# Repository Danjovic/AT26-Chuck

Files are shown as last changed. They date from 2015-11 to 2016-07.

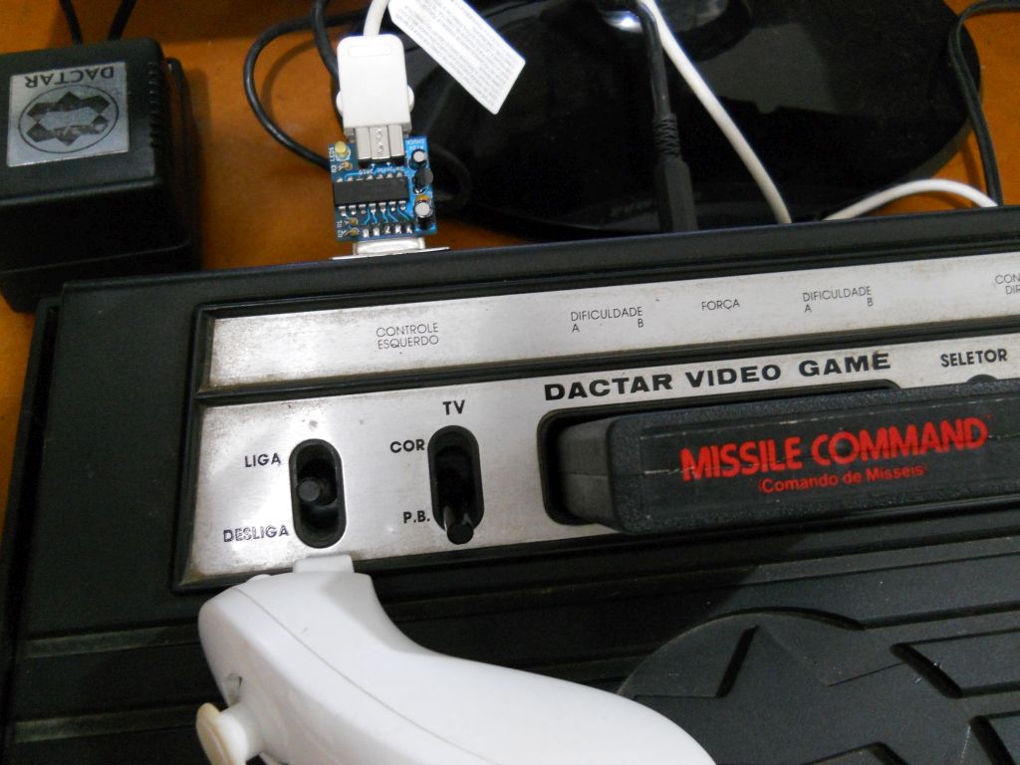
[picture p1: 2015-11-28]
Doc/DSCN6053.jpg

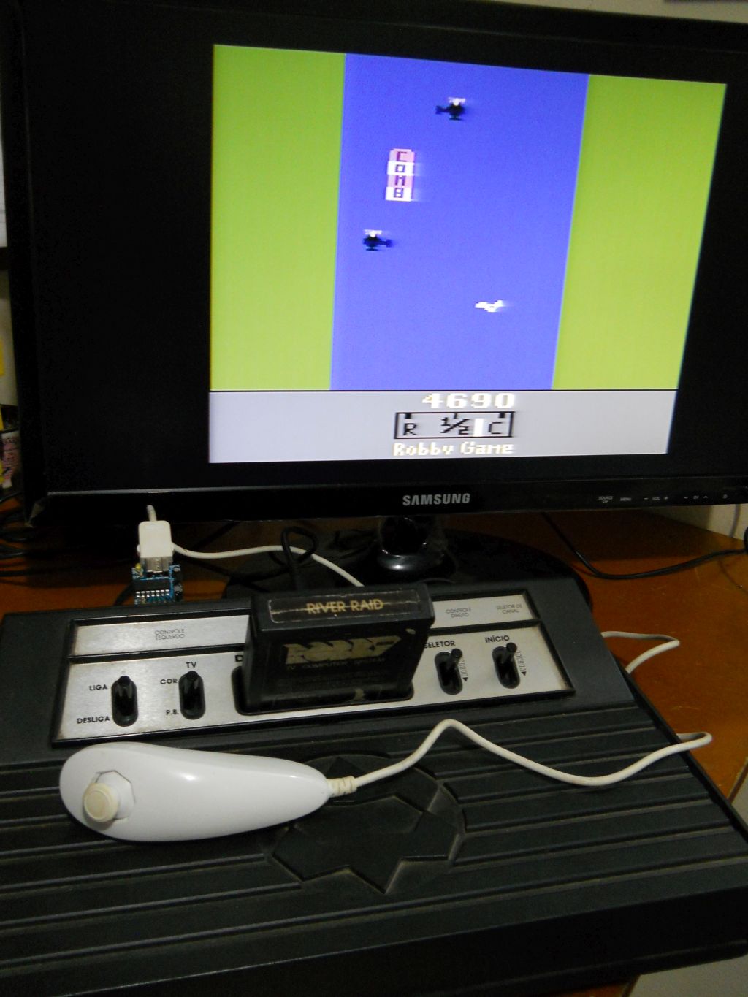
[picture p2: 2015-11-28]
Doc/DSCN6057.jpg

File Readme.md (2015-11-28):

# AT-26 Chuck
This project allow the use of a Wii Nunchuck for playing games with Atari 2600 and other video-games with compatible joystick port (like ZX Spectrum w/ Kempston).

The heart of the circuit is a PIC microcontroller that converts I2C data from Wii Nunchuck. into pressing of switches on the Atari Joystick.

The device can be programmed into several modes of operation, with or without the accelerometers and auto-fire. The configuration is stored in EEPROM.

All components are through hole and the board can be easily built at home.

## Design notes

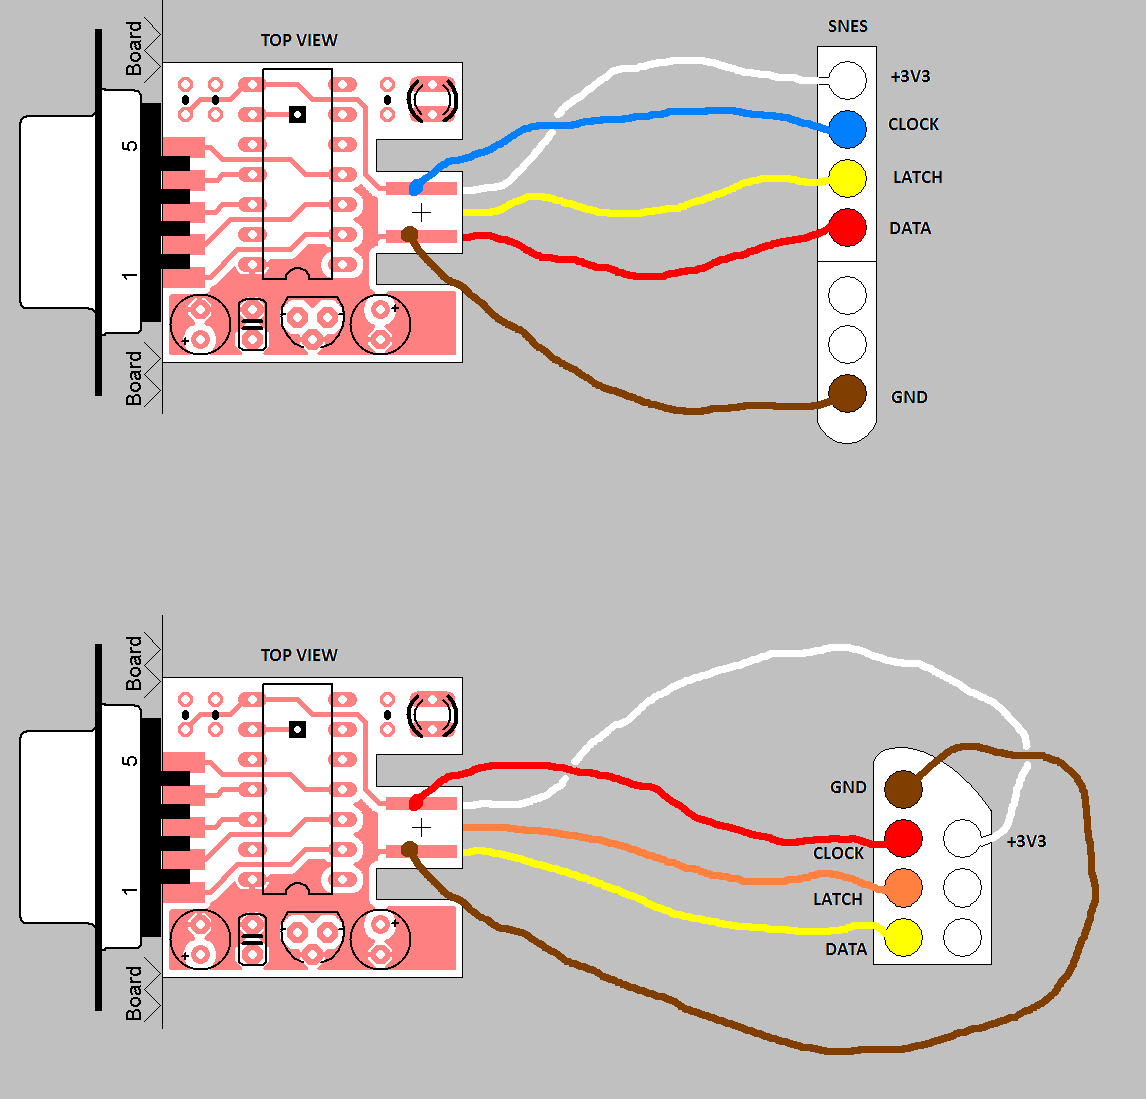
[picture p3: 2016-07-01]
Doc/Board Connections SNES - NES.png

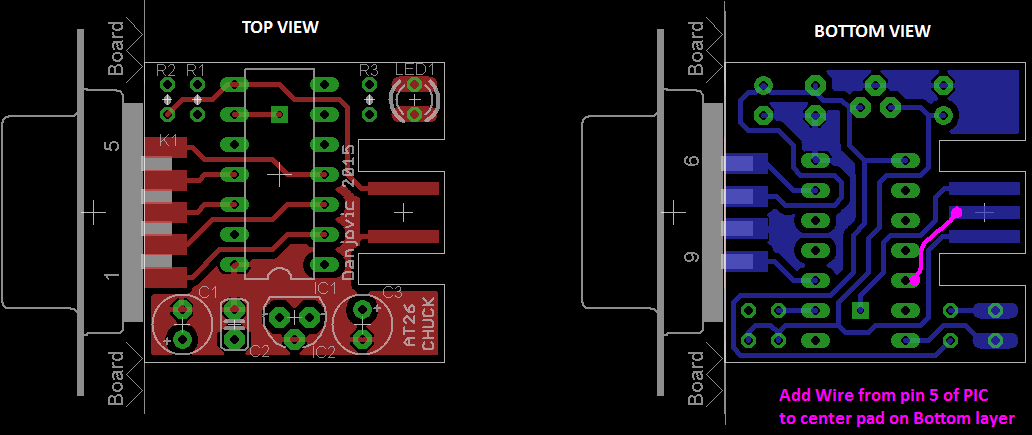
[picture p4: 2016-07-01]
Doc/Board MOD for SNES firmware.png

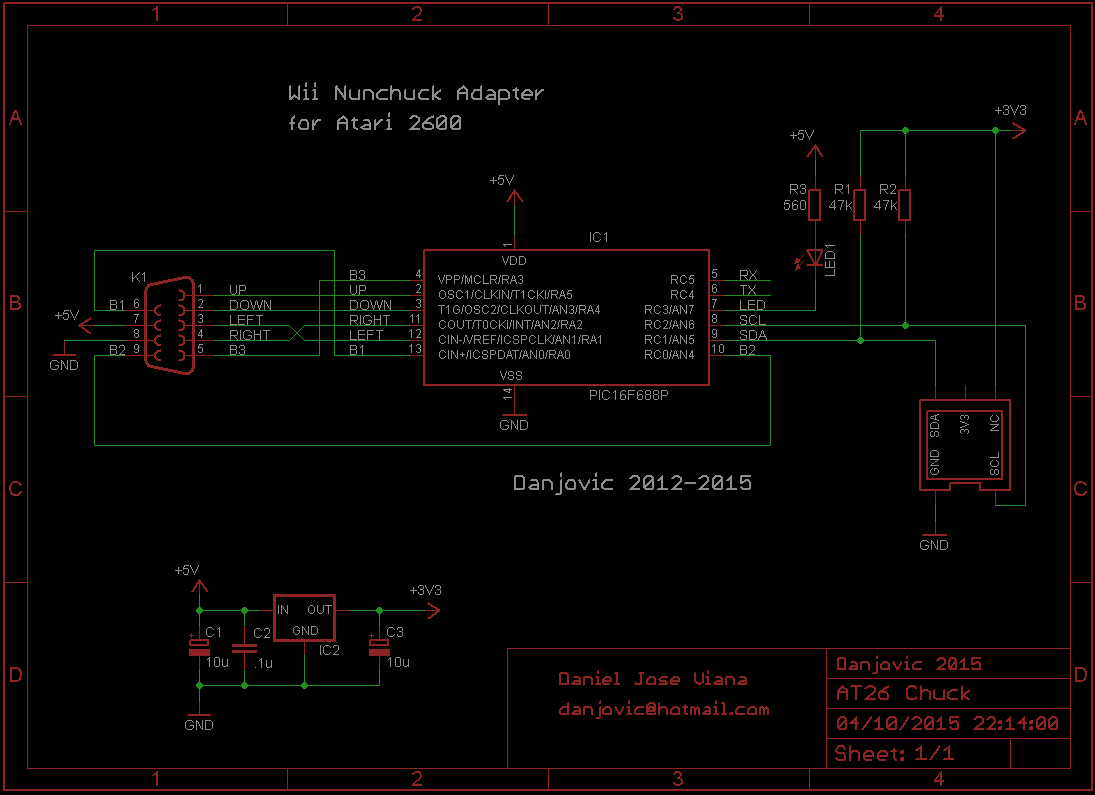
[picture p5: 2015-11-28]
Doc/AT26 Chuck-sch.png

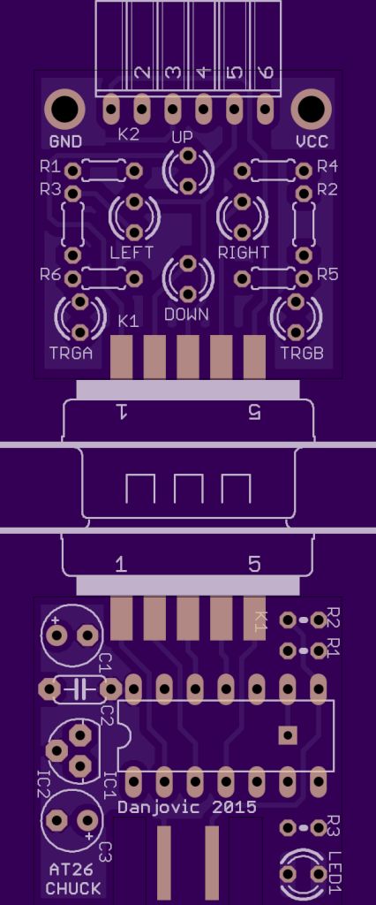
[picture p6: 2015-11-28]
Doc/AT26 both.jpg

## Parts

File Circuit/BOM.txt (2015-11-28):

# AT26-Chuck Bill of Materials

IC1   - PIC16F688, DIP14 Package PIC microcontroller 4K Flash, 14 pins
IC2   - 78L33 Voltage Regulator, TO92 package
LED1  - 3mm LED, Yellow 3mm LED, Yellow
C1,C3 - 10uF/16V Electrolytic Capacitor, radial
C2    - 100nf Polyester/Ceramic capacitor
R1,R2 - 47K 1/4W Resistor, 1/4 Watt
R3    - 560 Ohms 1/4W Resistor, 1/4 Watt
K1    - DB-9 Female SUBD connector, 9 pins, female, pins for soldering

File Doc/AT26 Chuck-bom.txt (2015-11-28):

Partlist exported from C:/Users/user/Desktop/Projetos/PIC/TK-Chuck/AT26 Chuck.sch at 04/10/2015 22:17:50

Qty Value      Device                  Part ID 
1   78L33      Voltage Regulator       IC2   
1   SUB09D     DB-9 Female Connector   K1    
1   LED        LED 3mm Yellow          LED1  
1   .1u        Ceramic Capacitor       C2 
2   10u        Electrolytic Capacitor  C1, C3
2   47k        1/8W Resistor           R1, R2
1   560        1/8W Resistor           R3    
1   PIC16F688P Microcontroller DIP14   IC1

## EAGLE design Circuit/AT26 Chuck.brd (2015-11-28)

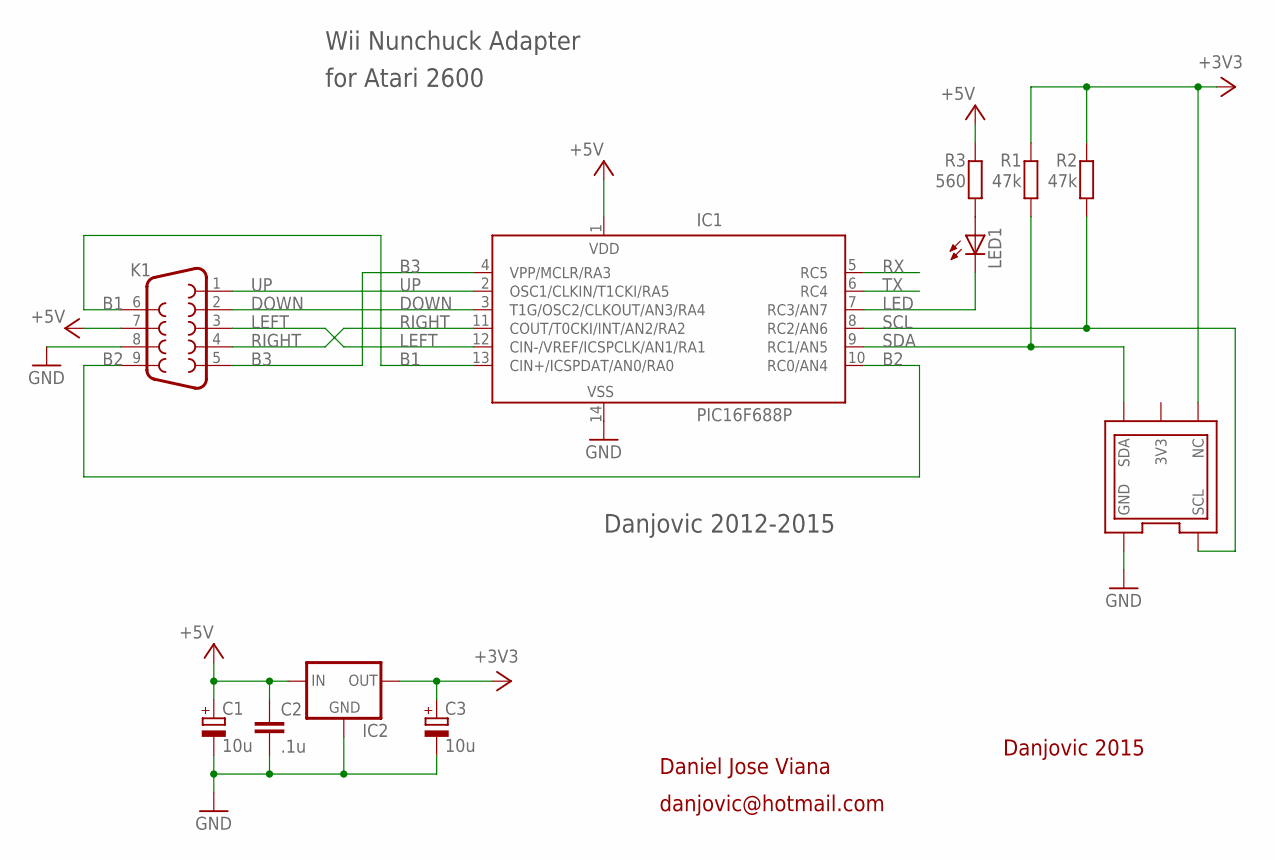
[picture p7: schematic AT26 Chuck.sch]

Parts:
C1, C3: 10u; E2,5-5
C2: .1u; C025-024X044L
IC1: PIC16F688P; DIL14
IC2: 78LXX78LXX_L; 78LXX_L
K1: F09D
LED1: LED3MM
R1, R2: 47k; 0204V
R3: 560; 0204V
U$1: NUNCHUCK; NUNCHUCK_SLOT

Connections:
+3V3: C3.+, IC2.OUT, R1.2, R2.2, U$1.NC
+5V: C1.+, C2.1, IC1.1 (VDD), IC2.IN, K1.7, R3.2
B1: IC1.13 (CIN+/ICSPDAT/AN0/RA0), K1.6
B2: IC1.10 (RC0/AN4), K1.9
B3: IC1.4 (VPP/MCLR/RA3), K1.5
DOWN: IC1.3 (T1G/OSC2/CLKOUT/AN3/RA4), K1.2
GND: C1.-, C2.2, C3.-, IC1.14 (VSS), IC2.GND, K1.8, U$1.GND
LED: IC1.7 (RC3/AN7), LED1.K (C)
LEFT: IC1.12 (CIN-/VREF/ICSPCLK/AN1/RA1), K1.3
unnamed: LED1.A, R3.1
RIGHT: IC1.11 (COUT/T0CKI/INT/AN2/RA2), K1.4
RX: IC1.5 (RC5)
SCL: IC1.8 (RC2/AN6), R2.1, U$1.SCL
SDA: IC1.9 (RC1/AN5), R1.1, U$1.SDA
TX: IC1.6 (RC4)
UP: IC1.2 (OSC1/CLKIN/T1CKI/RA5), K1.1

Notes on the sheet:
Danjovic 2015
Daniel Jose Viana
danjovic@hotmail.com
Danjovic 2012-2015
for Atari 2600
Wii Nunchuck Adapter

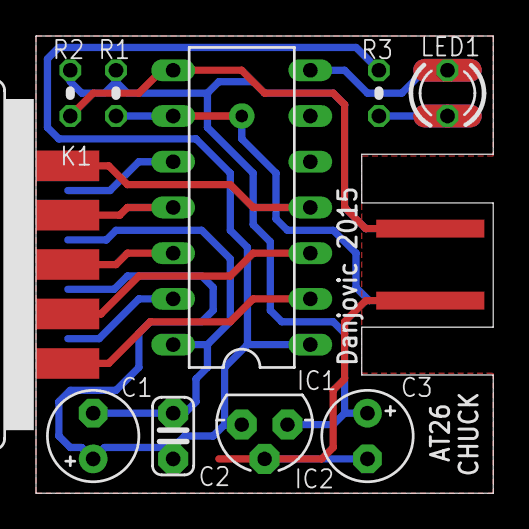
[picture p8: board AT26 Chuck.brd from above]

Board: 2 copper layers, 25.4 x 25.4 mm, 11 parts (1 on the bottom side), 14 nets.

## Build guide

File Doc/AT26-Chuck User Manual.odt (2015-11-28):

# Introduction

Thanks for using the AT26-Chuck interface, which was designed to allow using a Nunchuck controller in video game consoles and computers whose joystick ports are pin compatible with Atari 2600.

The Atari 2600 controller is a classic but has some ergonomic issues which are far better addressed by the Nunchuck controller specially the ergonomy and the ability to be used by left and righ handed player. Besides the Stick the interface allows the use of the accelerometers (for games like 'decathlon') and provides an autofire function.

The operating modes can be programmed and the configuration is stored into the adapter until a new operating mode is desired.

# Usage

Para utilizar a interface AT26-Chuck é necessário um controle tipo Nunchuck. Para saber se o seu controle é compatível com a interface, consulte o apêndice ao final do manual. Caso seu controle não conste na lista isso não significa que ele não funciona, mas apenas que ainda não foi testado.

## Uso normal - Controles Convencionais (com fio)

1. Conecte o Nunchuck no adaptador. A posição correta é com a “orelha” da alça voltada para baixo, como mostrado na figura abaixo.

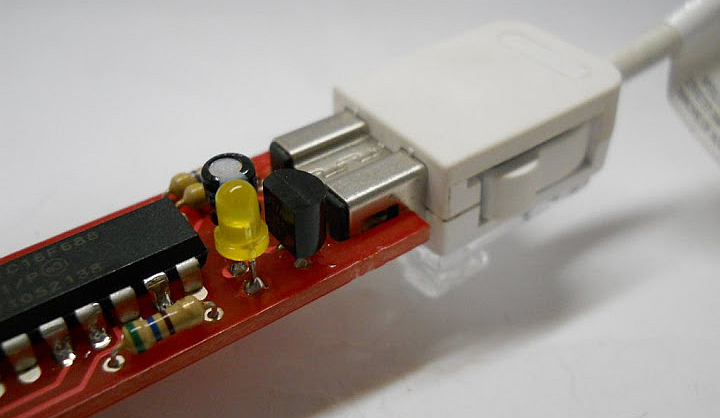
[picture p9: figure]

2. Em seguida conecte a interface no videogame. Se tudo estiver correto o LED deve permanecer apagado.
  Caso a Interface não consiga se comunicar com o adaptador, o LED deve continuamente piscar 3 vezes e em seguida apagar. Isso se repete até que um Nunchuck seja detectado. Se isso acontecer confira se o Nunchuck foi instalado na posição correta, ou tente utilizar um de marca ou modelo diferente.

## Programação - Controles Convencionais (com fio)

Assim que a interface é energizada e consegue se comunicar com o Nunchuck, ela verifica se algum dos botões está pressionado e se o direcional está fora do centro. Caso uma destas condições ocorra, a interface entra no modo de programação. Então, para programar a interface:

1. Conecte o Nunchuck no adaptador, conforme explicado no parágrafo anterior – Uso Normal.
2. Consulte a tabela de programação para saber as opções disponíveis. Acione os botões ou o direcional de acordo com o comportamento desejado e mantenha os nessa posição
3. Conecte a interface no videogame e aguarde uns instantes. O LED deve dar 5 piscadas rápidas, indicando que a programação foi bem sucedida.

Após a programação, o LED permanece apagado.

## Uso normal - Controles Sem Fio

1. Conecte o “Dongle” do Nunchuck sem fio no adaptador. A posição correta é com o LED virado para cima, como mostrado na figura abaixo. Oriente-se também pelo formato do encaixe.

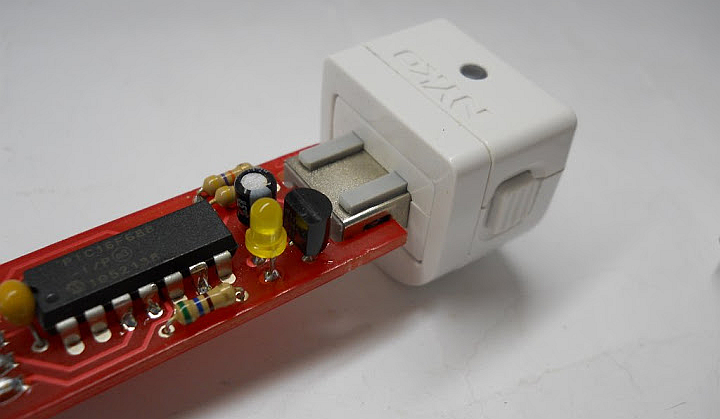
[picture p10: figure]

2. Em seguida conecte a interface no videogame. Se tudo estiver correto o LED deve permanecer apagado.
3. Pressione o botão “link” do controle sem fio. Nesse momento LED do Dongle e o do controle começam a piscar enquanto o processo de comunicação entre eles está sendo determinado. Enquanto isso acontece, o “dongle” pára de se comunicar com a interface AT26-Chuck, e o LED da interface AT26-Chuck deve continuamente piscar 3 vezes e em seguida apagar, indicando a falta de comunicação.
  Assim que o link entre o “dongle” e o controle é estabelecido, os LEDs de ambos param de piscar e permanecem acesos, ao passo em que o LED da interface AT26-Chuck pára de piscar e fica apagado,
  Caso a interface AT26-Chuck não consiga se comunicar com o “dongle”, o LED deve continuamente piscar 3 vezes e em seguida apagar. Se isso acontecer confira se o “dongle” do Nunchuck sem fio foi instalado na posição correta, ou tente utilizar um de marca ou modelo diferente.

## Programação - Controles Sem Fio

A programação da interface com controles sem fio é bem semelhante à programação dos controles convencionais, exceto pela etapa do link entre o “dongle” e o controle, conforme descrito no parágrafo acima. Para programar a interface com controles sem fio:

1. Conecte o “Dongle” do Nunchuck sem fio no adaptador. A posição correta é com o LED virado para cima, como mostrado na figura anterior. Oriente-se também pelo formato do encaixe.
2. Conecte a interface no videogame e aguarde uns instantes. Os LEDs da Interface, do “dongle” e do controle devem permanecer apagados, pois ainda não há link entre o “dongle” e o controle, muito embora haja comunicação entre a interface AT26-Chuck e o “dongle”
3. Consulte a tabela de programação para saber as opções disponíveis. Acione os botões ou o direcional de acordo com o comportamento desejado e mantenha-os nessa posição.
4. Pressione o botão “link” do controle sem fio. Nesse momento LED do Dongle e o do controle começam a piscar enquanto o processo de comunicação entre eles está sendo determinado. Enquanto isso acontece, o LED da interface AT26-Chuck deve continuamente piscar 3 vezes e em seguida apagar, indicando a falta de comunicação.
  Assim que o link entre o “dongle” e o controle é estabelecido, os LEDs de ambos param de piscar e permanecem acesos, ao passo em que o LED da interface AT26-Chuck deve dar 5 piscadas rápidas, indicando que a programação foi bem sucedida.

Após a programação, o LED permanece apagado.

## Tabela de Programação

A tabela abaixo descreve os comportamentos disponíveis. Condições diferentes das da tabela não têm efeito.

Botões | | Direcional | Comportamento
C | Z | | C | Z | Direcional
● | | Centro | B2 | B1 | Não muda
| ● | Centro | B1 | B1 | Não muda
● | | CIMA | B2+AF | B1 | Não muda
| ● | CIMA | B2+AF | B1+AF | Não muda
● | | BAIXO | B2 | B1+AF | Não muda
| ● | BAIXO | B1+AF | B1 | Não muda
| | CIMA | Não muda | Não muda | EixoY + Acelerômetro Y
| | BAIXO | Não muda | Não muda | Eixos X, Y somente
| | ESQUERDA | Não muda | Não muda | EixoX + Acelerômetro X
| | DIREITA | Não muda | Não muda | Eixos X, Y + Acelerômetros X, Y

B1 = Botão 1, B2 = Botão 2 (Kempston), AF = Auto Fire

## Auto-Calibração

Toda vez que se programa algum modo que utilize a ação conjunta de um dos acelerêmetros, a interface TK-Nunchuck efetua uma auto-calibração tomando como referência a posição do Nunchuck no momento em que o modo de programação ativado.

O valor de calibração fica armazenado em memória não volátil.

# Perguntas Frequentes

P: A interface TK-Nunchuck funciona na entrada original de joystick do TK-90/95 ou TK-85?

R:Não. Este adaptador foi feito para a interface Kempston, que por sua vez é compatível com a pinagem do Atari 2600.

P: A interface TK-Nunchuck funciona com a Interface 2 da Sinclair?

R: Não. Apesar da pinagem da Interface 2 ser bem parecida, ela não possui a linha de +5Volts no pino 7.

P: A interface TK-Nunchuck funciona com a Multiface 1?

R: Sim.

P: A Multiface 1, bem como algumas interfaces compatíveis com a Kempston possuem apenas 1 botão, mas o Nunchuck tem 2 botões (C e Z) Qual deles vai ser o botão de tiro?

R: Fisicamente a interface TK-Nunchuck tem 2 linhas para botões (B1 e B2), porém é possível programar os botões C e Z de forma a associar ambos os botões C e Z à linha de disparo B1.

P: É possível utilizar esta interface no MSX ou no Master System?

R: Sim, mas é necessário o uso de um adaptador (não incluso). O diagrama deste adaptador está nos apêndices deste manual

# Pinagem

A tabela abaixo traz a pinagem da interface AT26-Chuck.

CONECTOR DB-9 FÊMEA | PINO | FUNÇÃO
| 1 | CIMA
| 2 | BAIXO
| 3 | ESQUERDA
| 4 | DIREITA
| 5 | N/C
| 6 | BOTÃO 1
| 7 | +5V
| 8 | GND
| 9 | BOTÃO 2

# Compatibilidade

A tabela abaixo relaciona as marcas e os modelos de Nunchuck que já foram testados com a interface AT26-Chuck.

Marca | Modelo | Funciona | Observações
Nintendo | RVL-004 | Sim | Nintendo Original
Clone | não tem | Sim | Genérico
NYKO | KAMA | Sim | Controle sem fio, FCC ID SXJ87027-T

# Adaptadores

É possível construir adaptadores para outros video-games e microcomputadores, desde que possuam alimentação de +5Volts e GND e os direcionais sejam ativos em nível baixo. A tabela abaixo mostra uma comparação entre a pinagem dos conectores de joystick do Atari/Kempston com o MSX e o Master System.

CONECTOR DB-9 FÊMEA | PINO | ATARI / KEMPSTON | MSX | MASTER SYSTEM

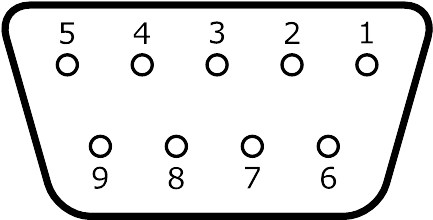
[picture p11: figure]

| 1 | CIMA | CIMA | CIMA
| 2 | BAIXO | BAIXO | BAIXO
| 3 | ESQUERDA | ESQUERDA | ESQUERDA
| 4 | DIREITA | DIREITA | DIREITA
| 5 | N/C | +5V | +5V
| 6 | BOTÃO 1 | BOTÃO 1 | BOTÃO 1
| 7 | +5V | BOTÃO 2 | N/C
| 8 | GND | N/C | GND
| 9 | BOTÃO 2 | GND | BOTÃO 2

## Adaptador para MSX

O diagrama abaixo ilustra como construir o cabo adaptador para o MSX.

## Adaptador para Master System

O diagrama abaixo ilustra como construir o cabo adaptador para o Master System.

AT26-Chuck – User Manual

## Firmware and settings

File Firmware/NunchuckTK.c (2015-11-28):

///////////////////////////////////////////////////////////////////////////////////////////////////////////////
///                                                                                                         ///
///                      Adaptador de Wii Nunchuck para joystick padrão ATARI                               ///
///                v1.01 25 de Outubro de 2012  - Daniel José Viana - danjovic@hotmail.com                  ///
///                - Basic Release                                                                          ///
///                                                                                                         ///
///                v1.1  12 de Fevereiro de 2013 - Daniel José Viana - danjovic@hotmail.com                 ///
///                - Changed I2C routines to support clock stretching                                       ///
///                - Simplified Nunhcuck detection. Works with oritginal, clone and wireless nunchucks      ///
///                                                                                                         ///
///                v1.11 16 de Fevereiro de 2013 - Daniel José Viana - danjovic@hotmail.com                 ///
///                - Changed blink engine and blink sequences for error and programming                     ///
///                                                                                                         ///
///                v1.12 25 de Maio de 2013 - Daniel José Viana - danjovic@hotmail.com                      ///
///                - Enhanced Initialization routine to detect initial position of the stick and buttons    ///
///                - Added Watchdog timer                                                                   ///
///                                                                                                         ///
///                v1.13 04 de Outubro de 2015 - Daniel José Viana - danjovic@hotmail.com                   ///
///                - Included conditional definitions for SQUARE INCH and TKCHUCK boards                    ///
///                - Code licence changed to GPL V2.0                                                       ///
///                                                                                                         ///
///                                                                                                         ///
///////////////////////////////////////////////////////////////////////////////////////////////////////////////


///////////////////////////////////////////////////////////////////////////////////////////////////////////////
///                                                                                                         ///
///                                    CONFIGURAÇÃO DO CHIP                                                 ///
///                                                                                                         ///
///////////////////////////////////////////////////////////////////////////////////////////////////////////////

#include <16f688.h>
#use delay(clock=8000000)
#fuses INTRC_IO, NOPROTECT, NOBROWNOUT, NOMCLR, WDT, PUT, 

//#define TKCHUCK
#define SQUARE


#rom  0x2100 = {0x13,0x78,0x78}
#ifdef TKCHUCK             // Definitions for SQUARE INCH Board
#rom  0x2108 = {"sn:0000 Prototipo"}
#endif

#ifdef SQUARE             // Definitions for SQUARE INCH Board
#rom  0x2108 = {"AT26-Chuck"}
#endif



///////////////////////////////////////////////////////////////////////////////////////////////////////////////
///                                                                                                         ///
///                                    DEFINIÇÃO DAS CONSTANTES                                             ///
///                                                                                                         ///
///////////////////////////////////////////////////////////////////////////////////////////////////////////////

#ifdef SQUARE             // Definitions for SQUARE INCH Board

#define BUTTON1  pin_a0
#define LEFT     pin_a1
#define RIGHT    pin_a2
#define BUTTON3  pin_a3
#define DOWN     pin_a4
#define UP       pin_a5

#define BUTTON2  pin_c0
#define P_SDA    pin_c1
#define P_SCL    pin_c2
#define LED      pin_c3
#define p_TXD    pin_c4
#define p_RXD    pin_c5

#endif


#ifdef TKCHUCK             // Definitions for TK Chuck Board

#define BUTTON2  pin_a0
#define RIGHT    pin_a1
#define LEFT     pin_a2
#define BUTTON3  pin_a3
#define DOWN     pin_a4
#define BUTTON1  pin_a5

#define UP       pin_c0
#define VPLUS33  pin_c1
#define P_SDA    pin_c2
#define LED      pin_c3
#define p_SCL    pin_c4
#define VMINUS   pin_c5

#endif 

#include "myI2C.h"

#define bit_b1c    0         // Bits do registro de configuração de operação
#define bit_b1z    1 
#define bit_b2c    2
#define bit_b2z    3
#define bit_afbc   4
#define bit_afbz   5
#define bit_useax  6
#define bit_useay  7

#define bit_Right  0         // Bits de opção de inicialização       
#define bit_Left   1
#define bit_Up     2  
#define bit_Down   3
#define bit_Z      4
#define bit_C      5

#define treshold 32          // Limiar em torno do centro da manete analógica
#define upper 128+treshold   // Limite superior
#define lower 128-treshold   // Limite inferior
#define tresholdA 64         // Limiar em torno do centro dos acelerômetros
#define MAX_TRIES 4           // Tentativas de leituras iguais na inicialização.

#define MSG_ERRINIT 0x08
#define MSG_CONFIG  0x3f
                          // Endereços na EEPROM 
#define config_address 0  // Configuração do adaptador
#define calibX_address 1  // Calibração do acelerometro X (MSB)
#define calibY_address 2  // Calibração do acelerometro X (MSB)

//#rom  0x2100={0x09,0x80,0x80}   // Inicializa endereços na eeprom


///////////////////////////////////////////////////////////////////////////////////////////////////////////////
///                                                                                                         ///
///                                       PROTOTIPO DAS FUNCOES                                             ///
///                                                                                                         ///
///////////////////////////////////////////////////////////////////////////////////////////////////////////////

//  Desativa as saídas, colocando-as em alta impedância 
void desativa_saidas(void);

//  Inicializa Nunchuck e retorna estado Z=não respondeu 
int1 init_Nunchuck(void);

//  Faz leitura do Nunchuck e retorna estado Z=não respondeu 
int1 read_Nunchuck();

//  Pisca o LED para indicar uma mensagem
void pisca_msg(char codigo);

//  Configura nunchuck conforme posição da manete analogica e botoes durante o startup
void configura_nunchuck(char opcoes);



///////////////////////////////////////////////////////////////////////////////////////////////////////////////
///                                                                                                         ///
///                                       INICIO DO PROGRAMA                                                ///
///                                                                                                         ///
///////////////////////////////////////////////////////////////////////////////////////////////////////////////

//
// Definição das Variáveis
//
char config;         // Configuração do adaptador
char opcao_startup;  // Opcao de inicializacao
char temp;           // variavel temporaria
char tries;          // quantidade de tentativas de leitura na inicialização

int1 B1C,            // Usa ou não Botão 1 conforme estado do botão C
     B1Z,            // Usa ou não Botão 1 conforme estado do botão Z
     B2C,            // Usa ou não Botão 2 conforme estado do botão C
     B2Z,            // Usa ou não Botão 2 conforme estado do botão Z
     AFBC,           // Auto Fire Botao C
     AFBZ,           // Auto Fire Botao Z
     USEAX,          // Opção de uso do acelerômetro X
     USEAY;          // Opção de uso do acelerômetro Y

int1 MODAF;          // Modulador do Auto Fire;
 
char X,Y;            // Eixos X e Y da manete mais .
int1 Z,C;            // Botões 

char sX,sY;          // Salva valor das manetes
//int1 sZ,sC;          // e dos botoes para check no startup

int16 AX,AY,AZ;      // Eixos X, Y e Z dos acelerômtros

int16 calibrAX,       // Valor de calibração do acelerometro X
      calibrAY;       // Valor de calibração do acelerometro Y

char AFModCont=0; // Contador do modulador do auto fire.

void main (void) {
  // init hardware
  setup_oscillator( OSC_8MHZ );
  setup_comparator(NC_NC_NC_NC);
  desativa_saidas();
  output_high(LED);
  delay_ms(100);  // espera alimentação estabilizar  
  setup_wdt(WDT_2304MS);

  // 
  // Loop principal
  //
  for (;;) {
    // Testa presença do nunchuck
    if (init_Nunchuck()) {
       delay_ms(50);
       if (read_nunchuck()) {
          // Checa opção de startup
          read_nunchuck();  
          sX=X; sY=Y;
          tries=MAX_TRIES;
          temp=20;

	      while (temp>0 && tries>0){
	           read_nunchuck();
	           if (X==sX && Y==sY)
	               tries--;
	           else {
		           sX=X; sY=Y;
		           tries=MAX_TRIES;
	           }
	           delay_ms(1);
	           temp--;	           
          }
          if (temp==0) break; // 

                            
          opcao_startup=0;
          if (Z)       opcao_startup|=(1<<bit_Z);    // Botao Z
          if (C)       opcao_startup|=(1<<bit_C);    // Botao C
          if (X>upper) opcao_startup|=(1<<bit_Right);// Right
          if (X<lower) opcao_startup|=(1<<bit_Left); // Left
          if (Y>upper) opcao_startup|=(1<<bit_Up);   // Up
          if (Y<lower) opcao_startup|=(1<<bit_Down); // Down
          if (opcao_startup)             // caso manete ou botoes não estejam em repouso na inicialização
             configura_nunchuck(opcao_startup);  // Checa opção escolhida e cria configuração de operação

          // Lê da EEPROM o modo de operação
          config=READ_EEPROM (config_address);  // Lê configuração da EEPROM
           
          if (config & (1<<bit_b1c)) B1C  =1; else B1C=0;
          if (config & (1<<bit_b1z)) B1Z  =1; else B1Z=0;
          if (config & (1<<bit_b2c)) B2C  =1; else B2C=0;
          if (config & (1<<bit_b2z)) B2Z  =1; else B2Z=0;
          if (config & (1<<bit_afbc)) AFBC  =1; else AFBC=0;
          if (config & (1<<bit_afbz)) AFBZ  =1; else AFBZ=0;
          if (config & (1<<bit_useax)) USEAX  =1; else USEAX=0;
          if (config & (1<<bit_useay)) USEAY  =1; else USEAY=0;

          // Lê da EEPROM os vetores de calibração dos acelerometros
          temp=READ_EEPROM (calibX_address);  // Calibração do Eixo X
          calibrAX=(int16)temp<<2;

          temp=READ_EEPROM (calibY_address);  // Calibração do Eixo Y
          calibrAY=(int16)temp<<2;

       } else break;  


         //                                                                                                  //
         //                Tarefa principal. Lê nunchuck, atualiza saídas conforme leitura                   //
         //           Se houver algum erro na leitura, sai e tenta inicializar novamente o nunchuck          //
         //                                                                                                  //
         while (read_nunchuck()) { 

            // Aguarda período de amostragem
            //
            restart_wdt();
            delay_ms(10); // while (!GO);
            // processa Auto Fire
            //
            AFModCont++;
            AFModCont&=3; // contador com modulo 4
            if (AFModCont==0) 
              MODAF=!MODAF;   
         

            // Atualisa saidas
            //
            // Botao 1
            if ( (Z&&B1Z&&(!AFBZ||MODAF))||(C&&B1C&&(!AFBC||MODAF)) ) output_low(BUTTON1);
              else output_float(BUTTON1);
            // Botao 2
            if ( (Z&&B2Z&&(!AFBZ||MODAF))||(C&&B2C&&(!AFBC||MODAF)) ) output_low(BUTTON2);
              else output_float(BUTTON2);
            // RIGHT
            if ( (X>upper) || ((AX>(calibrAX+tresholdA)) && USEAX)  ) output_low(RIGHT);
              else output_float(RIGHT);
            // LEFT
            if ( (X<lower) || ((AX<(calibrAX-tresholdA)) && USEAX)  ) output_low(LEFT);
              else output_float(LEFT);
            // UP
            if ( (Y>upper) || ((AY>(calibrAY+tresholdA)) && USEAY)  ) output_low(UP);
              else output_float(UP);
            // DOWN
            if ( (Y<lower) || ((AY<(calibrAY-tresholdA)) && USEAY)  ) output_low(DOWN);
              else output_float(DOWN);

           }  // while 
         //break;   // se alcançou aqui, houve um erro de comunicação.
         
      } 

    // Se alcançou este ponto, indica erro e tenta novamente após 1 segundo
    pisca_msg(MSG_ERRINIT);
    delay_ms(1000);

  } // for (loop principal)
}  // main



///////////////////////////////////////////////////////////////////////////////////////////////////////////////
///                                                                                                         ///
///                                    IMPLEMENTACAO  DAS FUNCOES                                           ///
///                                                                                                         ///
///////////////////////////////////////////////////////////////////////////////////////////////////////////////

//
//  Desativa as saídas, colocando-as em alta impedância 
//
void desativa_saidas(void) {
  output_float(UP);
  output_float(DOWN);
  output_float(LEFT);
  output_float(RIGHT);
  output_float(BUTTON1);
  output_float(BUTTON2);
  output_float(BUTTON3);
}


//
//  INIT NUNCHUCK - Testa se dispositivo responde no barramento I2C
//
//  Zero=Erro  NZ = Inicializou OK
int1 init_Nunchuck(void) {

  i2c_write_byte(true,false,0xa4);
  i2c_write_byte(false,false,0xf0);
  if (i2c_write_byte(false,true,0x55)) 
     return false; 
     
  i2c_write_byte(true,false,0xa4);
  i2c_write_byte(false,false,0xfb);
  if (i2c_write_byte(false,true,0x00)) 
     return false; 
  return true;
}



//
//  Faz leitura do Nunchuck e retorna estado. False=não respondeu 
//
int1 read_Nunchuck(){

  int8 temp;
  
  // Send request
  i2c_write_byte(true,false,0xa4);  
  if (i2c_write_byte(false,true,0x00))  // if not acked, return false
     return false; 
  delay_ms(1);           // consider removing this

  // receive report 
  i2c_write_byte(true,false,0xa5);  // send read request. maybe check an ack here
  
  X  = i2c_read_byte(false, false);       // 1st byte: X axis
  Y  = i2c_read_byte(false, false);       // 2nd byte: Y axis
  AX = ((int16)i2c_read_byte(false, false)<<2);  // 3rd byte: Accelerometer X, msbits
  AY = ((int16)i2c_read_byte(false, false)<<2);  // 4th byte: Accelerometer Y, msbits
  AZ = ((int16)i2c_read_byte(false, false)<<2);  // 5th byte: Accelerometer Z, msbits
  temp      =  i2c_read_byte(true, true);        // 6th byte: Accelerometers lsbits, buttons C,Z

  AX+=((temp>>2) & 0x03);  // insert LSBits from accelerometers
  AY+=((temp>>4) & 0x03);
  AZ+=((temp>>6) & 0x03);

  C=( (temp&0x02)==0);
  Z=( (temp&0x01)==0);
  
  return true;
} //read_nunchuck


//
//  Pisca o LED para indicar uma mensagem
//
void pisca_msg(char codigo) {
//  int k;
  desativa_saidas();

  for (;codigo!=0x01;codigo>>=1) {
      output_low(LED); // acende led
      if (codigo & 1 ) {// Piscada rapida
         delay_ms(100);
         output_high(LED); // apaga led   
         delay_ms(200); 
      } else {
         delay_ms(500); // piscada lenta
         output_high(LED); // apaga led   
         delay_ms(150);         
      }   
  } // for

} //pisca_msg



//
//   Configura nunchuck conforme posição da manete analogica e botoes durante o startup
//
void configura_nunchuck(char opcoes) {
   char conf,a;
   
   conf=READ_EEPROM(config_address);
   switch (opcoes) { // opcoes dos botoes 

     // C + neutro  ->  B2=C, Z=B1       
     case (1<<bit_C):          
                     conf&=~((1<<bit_b1c)|                          (1<<bit_b2z )|(1<<bit_afbc)|(1<<bit_afbz));    
                     conf|= (             (1<<bit_b1z)|(1<<bit_b2c)                                          );                    
                     break;

     // Z + neutro  ->  C=B1, Z=B1
     case (1<<bit_Z):     
                     conf&=~(                          (1<<bit_b2c)|(1<<bit_b2z )|(1<<bit_afbc)|(1<<bit_afbz));    
                     conf|= ((1<<bit_b1c)|(1<<bit_b1z)                                                       ); 
                     break;

     // C + up  ->  C=B2+AF, Z=B1  
     case ((1<<bit_C)+(1<<bit_Up)):       
                     conf&=~((1<<bit_b1c)|                          (1<<bit_b2z )|              (1<<bit_afbz));    
                     conf|= (             (1<<bit_b1z)|(1<<bit_b2c)|              (1<<bit_afbc)              ); 
                     break;

     // Z + up  ->  C=B2+AF, Z=B1+AF  
     case ((1<<bit_Z)+(1<<bit_Up)):       
                     conf&=~((1<<bit_b1c)|                          (1<<bit_b2z )                            );    
                     conf|= (             (1<<bit_b1z)|(1<<bit_b2c)|              (1<<bit_afbc)|(1<<bit_afbz)); 
                     break;

    // C + down  ->  C=B2, Z=B1+AF 
    case ((1<<bit_C)+(1<<bit_Down)):      
                     conf&=~((1<<bit_b1c)|                          (1<<bit_b2z )|(1<<bit_afbc)              );    
                     conf|= (             (1<<bit_b1z)|(1<<bit_b2c)|                            (1<<bit_afbz)); 
                     break;

     // Z + down  ->  C=B1+AF, Z=B1 
     case ((1<<bit_Z)+(1<<bit_Down)):      
                     conf&=~(                          (1<<bit_b2c)|(1<<bit_b2z )|              (1<<bit_afbz));    
                     conf|= ((1<<bit_b1c)|(1<<bit_b1z)|                           (1<<bit_afbc)              ); 
                     break;


     // opcoes dos acelerometros

     // up  ->  Use AY
     case (1<<bit_Up):               
                     conf&=~((1<<bit_useax)               );    
                     conf|= (               (1<<bit_useay));
                     a=(int8)(AY>>2);                 // MSBits do valor do acelerômetro lido na inicialização
                     WRITE_EEPROM(calibY_address,a);  // Armazena na EEPROM
                     break;

     // down  ->  desativa ação dos acelerometros
     case (1<<bit_Down):            
                     conf&=~((1<<bit_useax)|(1<<bit_useay));    
                   //conf|= ((1<<bit_useax)|(1<<bit_useax));
                     break;

     // left  ->  Usa acelerometro no eixo X
     case (1<<bit_Left):            
                     conf&=~(               (1<<bit_useay));    
                     conf|= ((1<<bit_useax)               );
                     a=(int8)(AX>>2);                 // MSBits do valor do acelerômetro lido na inicialização
                     WRITE_EEPROM(calibX_address,a);  // Armazena na EEPROM
                     break;

     // right  ->  Usa acelerometro nos eixos X e Y
     case (1<<bit_Right):           
                   //conf&=~((1<<bit_useax)|(1<<bit_useay));    
                     conf|= ((1<<bit_useax)|(1<<bit_useay));
                     a=(int8)(AY>>2);                 // MSBits do valor do acelerômetro lido na inicialização
                     WRITE_EEPROM(calibY_address,a);  // Armazena na EEPROM
                     a=(int8)(AX>>2);                 // MSBits do valor do acelerômetro lido na inicialização
                     WRITE_EEPROM(calibX_address,a);  // Armazena na EEPROM
                     break;
   
   }  // switch  
   WRITE_EEPROM(config_address,conf);  // Atualiza opções na EEPROM

   pisca_msg(MSG_CONFIG);

} // configura_nunchuck

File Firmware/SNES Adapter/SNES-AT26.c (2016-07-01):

///////////////////////////////////////////////////////////////////////////////////////////////////////////////
///                                                                                                         ///
///                         Adaptador de controde de SNES para padrão ATARI                                 ///
///                           Baseado nos projetos AT26-Chuck e Digi[S]NES                                  ///
///                                                                                                         ///
///                            Daniel José Viana 2016 - danjovic@hotmail.com                             
///                                                                                                         ///
///      v0.7 30 de junho de 206 - Daniel José Viana                                                            ///
///      Versao Basica  - Basic Release                                                                          ///
///                                                                                                         ///
///                           Este codigo e livre conforme licenca GPL V2.0                                 ///
///                                                                                                         ///
///////////////////////////////////////////////////////////////////////////////////////////////////////////////


///////////////////////////////////////////////////////////////////////////////////////////////////////////////
///                                                                                                         ///
///                                    CONFIGURAÇÃO DO CHIP                                                 ///
///                                                                                                         ///
///////////////////////////////////////////////////////////////////////////////////////////////////////////////

#include <16f688.h>
#use delay(clock=8000000)
#fuses INTRC_IO, NOPROTECT, NOBROWNOUT, NOMCLR, WDT, PUT, 

#rom  0x2108 = {"SNES to Atari2600"}


///////////////////////////////////////////////////////////////////////////////////////////////////////////////
///                                                                                                         ///
///                                    DEFINIÇÃO DAS CONSTANTES                                             ///
///                                                                                                         ///
///////////////////////////////////////////////////////////////////////////////////////////////////////////////

#define BUTTON1  pin_a0
#define LEFT     pin_a1
#define RIGHT    pin_a2
#define BUTTON3  pin_a3  // Not used in Atari 2600
#define DOWN     pin_a4
#define UP       pin_a5

#define BUTTON2  pin_c0  // Not used in Atari 2600
#define datapin  pin_c1  // Data IN line
#define clockPin pin_c2  // Clock OUT line
#define LED      pin_c3
#define p_TXD    pin_c4  
#define latchPin pin_c5  // Latch line


// Compatibilidade com funcoes de IO do Arduino do projeto Digi[S]NES
#define uint16_t unsigned int16
#define uint8_t unsigned char
#define digitalWrite output_bit
#define digitalRead  input
#define HIGH 1
#define LOW 0

///////////////////////////////////////////////////////////////////////////////////////////////////////////////
///                                                                                                         ///
///                                       PROTOTIPO DAS FUNCOES                                             ///
///                                                                                                         ///
///////////////////////////////////////////////////////////////////////////////////////////////////////////////

//  Desativa as saídas, colocando-as em alta impedância 
void desativa_saidas(void);

//  Faz leitura do controle do SNES 
void read_SNES();

//  Pisca o LED para indicar uma mensagem
void pisca_msg(char codigo);

inline void Pulse_clock(void);

// Get buttons state. 
uint16_t get_buttons(void);

///////////////////////////////////////////////////////////////////////////////////////////////////////////////
///                                                                                                         ///
///                                       Definição das Variáveis                                           ///
///                                                                                                         ///
///////////////////////////////////////////////////////////////////////////////////////////////////////////////

uint16_t Buttons16;
uint8_t Buttons_low;
uint8_t Autofire_modulation,flip_flop=0;

///////////////////////////////////////////////////////////////////////////////////////////////////////////////
///                                                                                                         ///
///                                       INICIO DO PROGRAMA                                                ///
///                                                                                                         ///
///////////////////////////////////////////////////////////////////////////////////////////////////////////////
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

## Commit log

2015-11-28 Basic Release
    [AT26 Chuck.brd, AT26 Chuck.sch]
2015-11-28 Added Gerber Files
